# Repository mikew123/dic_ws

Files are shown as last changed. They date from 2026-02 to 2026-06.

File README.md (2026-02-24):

# Platform control

The platform creates a wifi signal that needs to be connected to:<br>
SSID: "tech" PASSWORD: "Art723!!"<br>
Use a web browser to connect to "htpp://192.168.4.1"<br>
Configure the HOME offset degrees and periodic rotation period and degrees of rotation.<br>
<br>
The platform must be put in the "HOME" position by pressing the "HOME" button which points in the same direction each time after the homeing sequence completes. The homing sequence rotates 1 or 2 times before stopping.<br>
After the homeing is complete the "RUN" button starts the periodic rotations. The platform rotates the amount set by the periodic rotation amount and stops until the the next rotation starts. The rotations occur an the precise intervlas set by the periodic period.<br>

# Platform views

View of the bottom panel of the platform from the top. The housing in the center send the AC power to the top using a rotary coupler and has a 6" bearing on its top which fits into the ring on the bottom panel. There are 4 caster wheels and a large motor with a drive wheel which causes the top panel to rotate. Next to the motor is the motor controller. The limit switches are mounted so that the humps on the top panel activate them as the pass over the switch. <br>
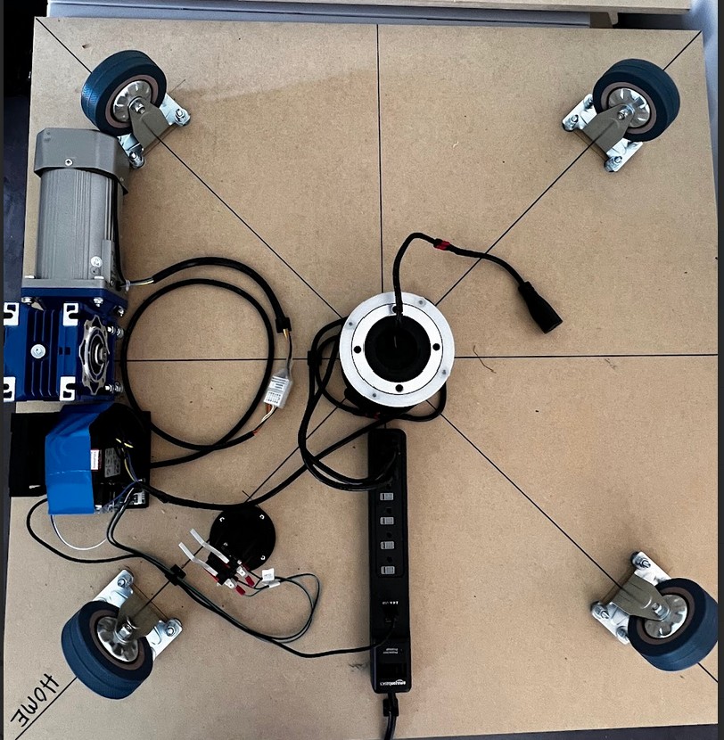
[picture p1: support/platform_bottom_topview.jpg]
platform bottom top view
 <br>
View of the top panel of the platform from the bottom. The center ring is used to keep the top panel centered using the bearing on the bottom panel. There are 4 humps which activate the limit switches on the bottom panel. <br>
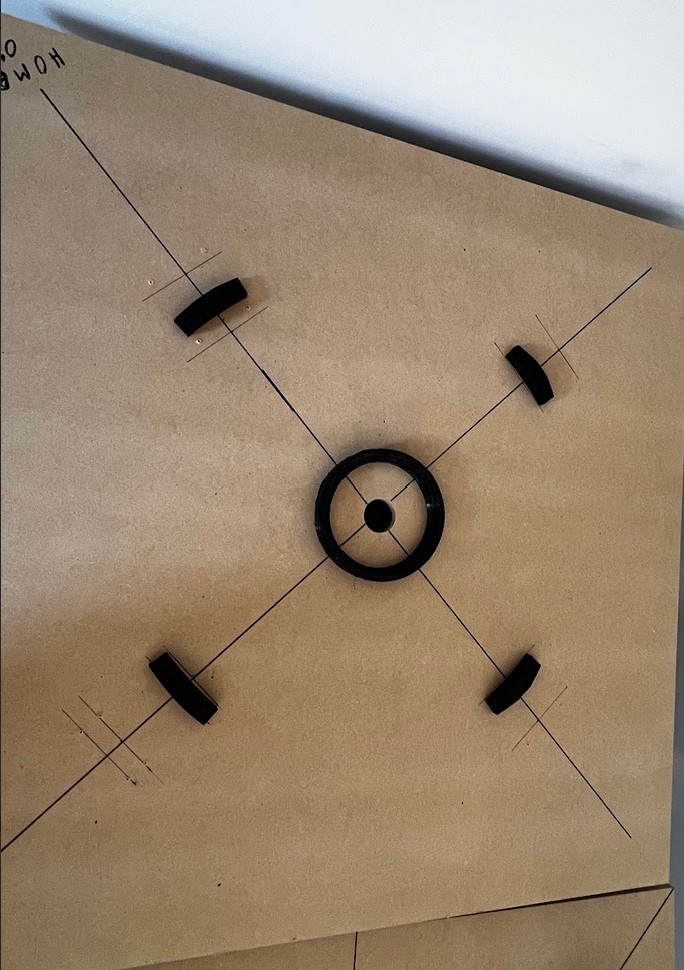
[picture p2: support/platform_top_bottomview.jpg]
platform top bottom view
 <br>
View of the bottom panel of the platform from the side.
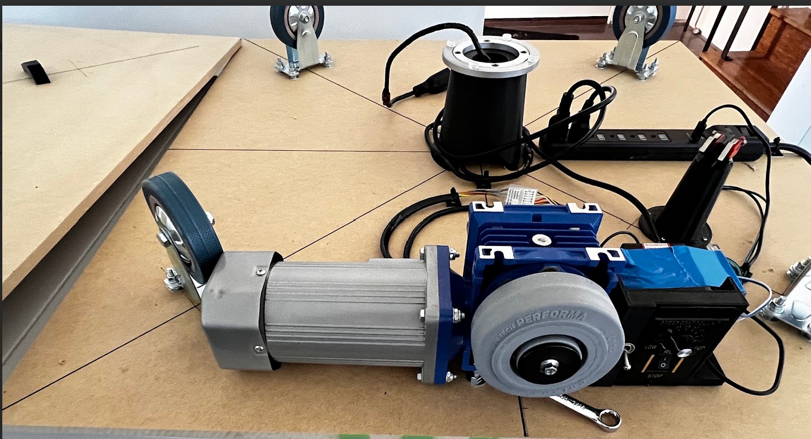
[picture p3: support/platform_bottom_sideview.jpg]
platform bottom sideview
 <br>
The height of the drive wheel cn be adjusted using the bolt nuts to raise the motor. The bolt threads provide  fine resolution in height adjustment.
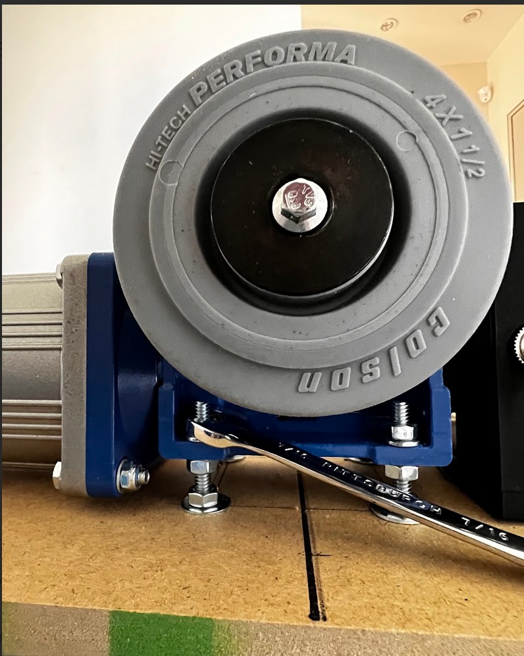
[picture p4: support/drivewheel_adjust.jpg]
drivewheel adjust
 <br>
View of the motor controller. The rotation rate is controlled by the SPEED knob. The switch to the left controlls CW and CCW platform rotation. The microcontroller on the right side (blue light) has the wifi interface and performs the periodic rotations by turning the motor ON/OFF.
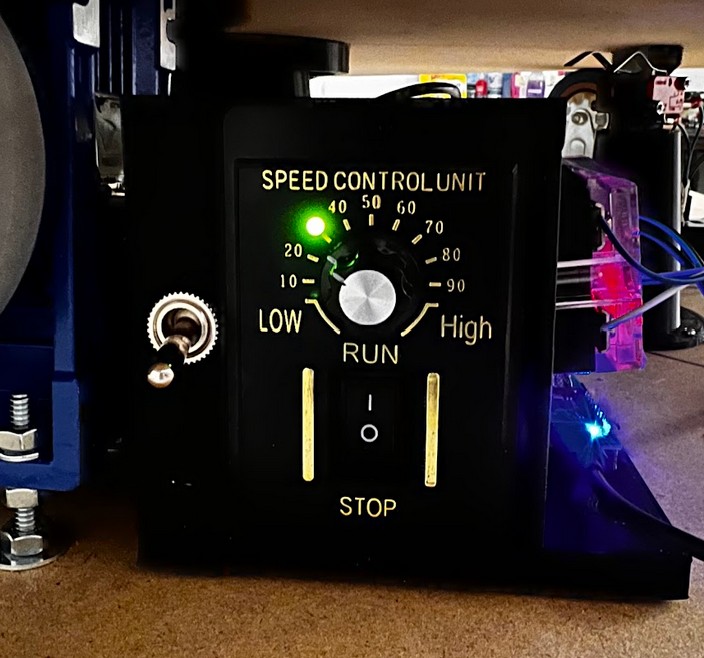
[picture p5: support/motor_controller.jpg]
motor_controller
 <br>
Top of the webpage which has the configuration.
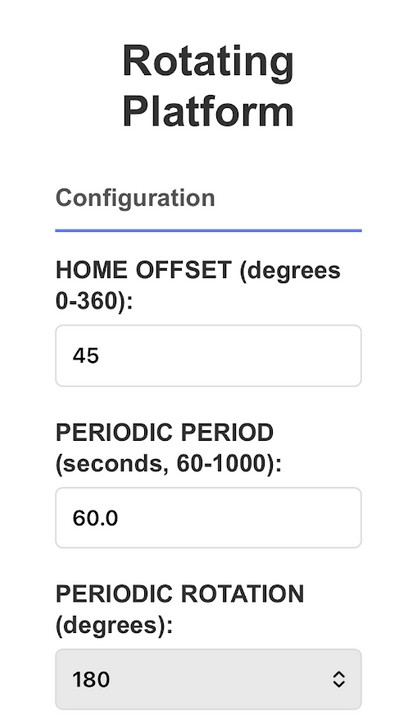
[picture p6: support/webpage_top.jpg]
 <br>
Bottom of the webpage which has the control buttons.
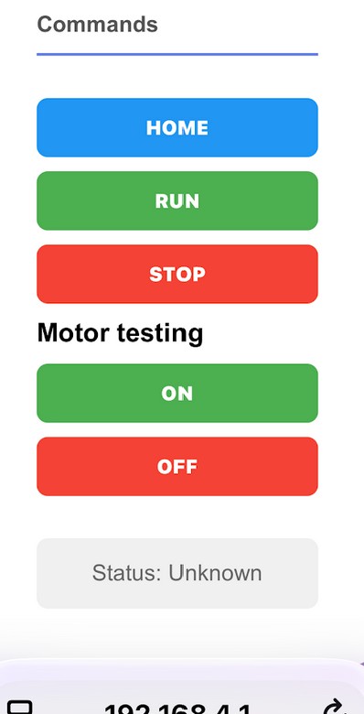
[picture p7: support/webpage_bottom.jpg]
platform bottom sideview
 <br>

# Micro-controller

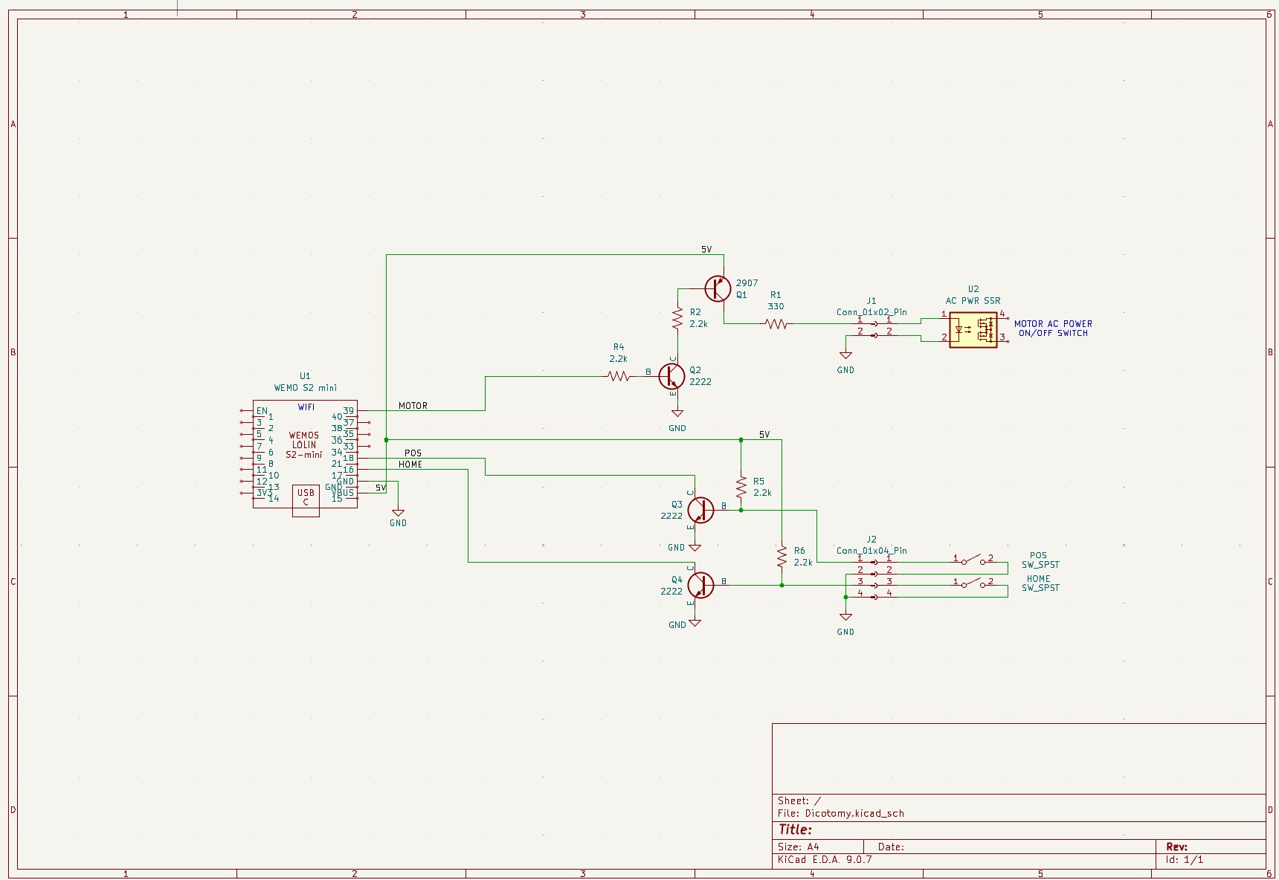
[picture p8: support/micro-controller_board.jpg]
micro controller board
 <br>
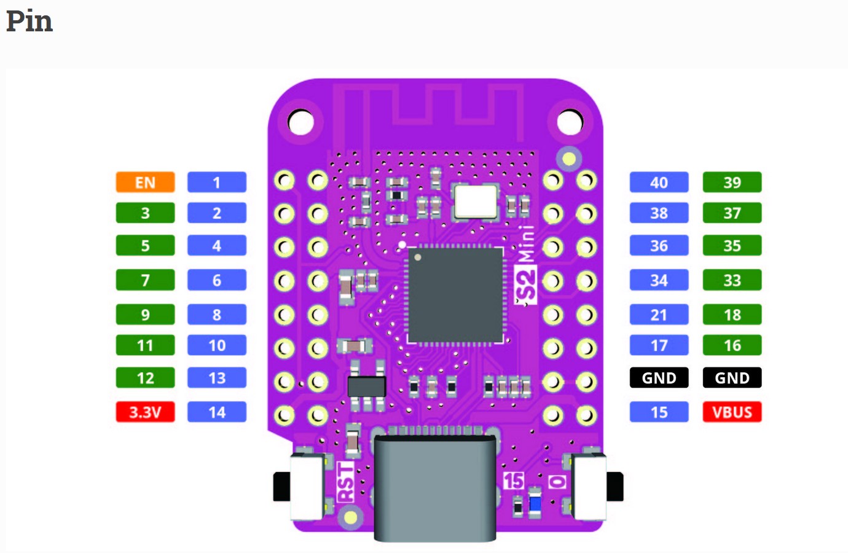
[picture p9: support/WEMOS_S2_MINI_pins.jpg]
micro controller
 <br>

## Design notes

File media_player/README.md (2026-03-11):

# Dicotomy of Passion Media player
There are 2 projectors in the house pointing out different side of the house in the rotating sculpture which are playing different videos on a timed loop. The will be audio from each video eminating from the side of the house the video is playing from. There is AC power in the sculpure to run the media.<br>
The player could be a MAC/PC or a Raspberry Pi with 2 HDMI interfaces. The audio would come from the 3.5mm audio jack on each of the 2 projectors. The sound can come from 2 portable speakers using the audio signal from the 3.5mm audio jacks. The portable speakers can have charging cables plugged in supplying power instead of only the internal batteries.<br>

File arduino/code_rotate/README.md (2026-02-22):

# Rotating Platform Control - code_rotate

## Overview
Arduino code for the ESP32 (WEMOS S2-mini) microcontroller that controls a rotating platform. The platform can be rotated to a HOME position and then periodically rotated with precise timing and no accumulated drift.

## Hardware Interface

### Motor Control
- **Pin 39**: Motor control digital output
  - HIGH: Motor ON
  - LOW: Motor OFF

### Position Limit Switches
Two limit switches with transistor voltage level converters (5V to ESP32 compatible):

- **Pin 16 (HOME_SWITCH_PIN)**: HOME position limit switch
  - Triggered when platform reaches position 0 (HOME position)
  - Used to establish home position reference
  - Part of position detection system (every 90 degrees)

- **Pin 18 (POSITION_SWITCH_PIN)**: Position limit switch
  - Triggered at each 90-degree offset from HOME
  - Positions: 90°, 180°, 270° (HOME is 0°)
  - Used to measure rotation speed (RPM) between triggers
  - Also used to detect HOME position (both switches trigger at home)

### Switch Characteristics
- Both switches use LOW to HIGH transitions to signal detection
- 100ms debounce time required to filter glitches
- All 4 discrete positions (0°, 90°, 180°, 270°) are detectable

## WiFi & Web Interface

### Network
- **Mode**: Access Point (AP)
- **SSID**: "dicotomy"
- **Password**: "passion"
- **Port**: 80 (HTTP)

### Web Page Features
The web interface provides configuration and control:

#### Configuration Parameters
1. **HOME OFFSET** (0-360 degrees)
   - Degrees to rotate after HOME switch is detected
   - Establishes the starting position for periodic rotations
   - Valid range: 0-360

2. **PERIODIC PERIOD** (60-1000 seconds, 1 decimal place)
   - Time between start of each periodic rotation
   - Maintains precise timing with no accumulated drift
   - Example: 60.0 means rotations start every 60 seconds

3. **PERIODIC ROTATION** (degrees in 90° increments)
   - Valid options: 90, 180, 270, 360, 450, 540, 630, 720
   - Amount to rotate in each periodic cycle
   - Example: 540 = 1.5 rotations

#### Commands
- **HOME**: Rotate platform to HOME position + HOME OFFSET
  - Motor must be OFF to start HOME sequence
  - Detects HOME switch twice, then rotates to offset position
  
- **RUN**: Start periodic rotations
  - Only available after HOME sequence completes
  - Rotations start immediately and repeat every PERIODIC PERIOD
  - No accumulated timing drift

- **STOP**: Stop motor and periodic rotations
  - Halts any active rotation
  - Motor transitions to OFF state

## Motion Control Details

### Rotation Tracking
- Four hardware-detected positions: 0° (HOME), 90°, 180°, 270°
- Additional positions calculated based on HOME OFFSET (up to 360°)
- Rotation speed (RPM) measured from time between POSITION switch triggers (90° apart)

### HOME Sequence (Example)
1. User clicks HOME button
2. Motor rotates until HOME switch triggers (first detection)
3. Motor continues until HOME switch triggers again (second detection)
4. Motor rotates additional HOME OFFSET degrees
   - If offset divides evenly by 90°, uses position switches
   - Remaining degrees (< 90°) calculated using estimated RPM
5. Motor stops at final home position
6. Platform ready for RUN command

### Periodic Rotation Sequence (Example)
1. Home position confirmed
2. User clicks RUN button
3. First rotation starts immediately
4. Platform rotates PERIODIC_ROTATION degrees (using position switches and time)
5. Motor stops
6. Precisely PERIODIC_PERIOD seconds after RUN was issued, rotation #2 starts
7. Rotations continue: #3 starts at 2×PERIODIC_PERIOD, etc.
8. No accumulated time drift between rotations

### Timing Precision
- Rotations are scheduled from the RUN button time, not from motor stop time
- This eliminates accumulated drift even if individual rotations take slightly different times
- Each periodic rotation starts at: RUN_TIME + (N × PERIODIC_PERIOD)

## Code Architecture

### State Machine
```
MOTOR_OFF → HOMING → HOME_COMPLETE → PERIODIC_RUNNING ↔ PERIODIC_WAITING
   ↑                      ↑                              ↑
   +--- STOP command -----+-------------- STOP command --+
```

### Key Functions
- `updateSwitchStates()`: Debounces limit switch inputs
- `onHomeSwitchTriggered()`: Handles HOME switch logic
- `onPositionSwitchTriggered()`: Tracks rotation and measures RPM
- `updateMotorControl()`: Manages motor timing and state transitions
- `handleHome()`, `handleRun()`, `handleStop()`: Web command handlers

### Important Variables
- `motorState`: Current operational state
- `homeCountDuringHome`: Tracks HOME switch triggers during homing
- `positionCountDuringRotation`: Counts 90° position switches
- `estimatedRPM`: Calculated speed from switch timing
- `runCommandTime`: Reference time for periodic rotation scheduling
- `lastRotationNumber`: Prevents multiple starts of same rotation

## Validation Rules
All configuration values are validated:
- HOME OFFSET: Must be 0-360 (integer)
- PERIODIC PERIOD: Must be 60-1000 (float with 1 decimal)
- PERIODIC ROTATION: Must be one of [90, 180, 270, 360, 450, 540, 630, 720]

Invalid configurations are rejected with error messages.

## Serial Debug Output
Monitor serial port (115200 baud) for debugging information:
- WiFi connection status
- Web server startup
- Switch trigger events
- RPM measurements
- Command execution logs
- State transitions

## Safety Notes
- Motor OFF when power applied (safe default)
- HOME sequence required before RUN
- STOP always available to halt rotation
- Configuration validates all inputs
- 100ms debounce prevents false triggers

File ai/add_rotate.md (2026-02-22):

# Overview
Modify the existing arduino project "arduino/code_onoff" code which was created with the requirements in the "add_onoff.md" file to make a new arduino project "arduino/code_rotate". The platform can be rotated to a HOME position then periodically rotated relative to the HOME position. Fix any errors after generating the code.

# Hardware interface to platform
The platform motor control and position limit switch sensors connect to digital pins of the ESP32.

## Position limit switches
There are 2 limit switches with transitors for voltage level conversion. High is when the switches are at the home location (position 0) or one of the 3 positions at 90, 180 and 270 degree offsets from HOME. 
- The HOME switch is on pin 16. The home position switch is is triggered at position 0 which sets the platform alignment.
- The POSITION switch is on pin 18. The position switch gets triggered at each of the 3 positions 90 degrees apart.

# Ethernet/wifi
Modify the existing served web page with configuration inputs and 2 new buttons.

### Configurations
Validate all configurations are positive.
- HOME OFFSET: 
Degrees offset after the HOME limit switch is sensed. This establishes the platform periodic rotation start position after the HOME command is given. This is positive integer in degrees. The range is 0 to 360 degrees.
- PERIODIC PERIOD: The amount of time between start of each periodic rotation. This is positive floating seconds with 1 decimal place. The range is limited to 60 to 1000 seconds.
- PERIODIC ROTATION: This is the amount of rotation the platform performs after each periodic positioning period. It is a integer pick list with 90 degrees incriments of [90, 180, 270, 360, 450, 540, 630, 720].

### Commands
Add these new command buttons to the existing ON and OFF buttons
- HOME: Rotate the platform to the HOME OFFSET from the last HOME limit switch trigger. The motor must be OFF to start the HOME sequence.
- RUN: Start the periodic rotations. The motor must be OFF/STOP and a HOME sequence executed.
- STOP: Stop the periodic rotations, turns the motor OFF.

## Details
- The code starts in the MOTOR OFF state
- Any motor ON/OFF commands stop the periodic rotations if active.
- The HOME sequence can be started any time the motor is OFF/STOP
- The RUN sequence can only perform after the HOME sequence is finished and the motor is OFF/STOP.

### Rotations in degrees.
The HOME and POSITION limit switches create a command signal when switching LOW to HIGH. This transition LO to HIGH and HIGH to LOW can have glitches which must be filtered out, use a 100 ms requirment to detect HI or LOW
- There are only 4 hardware detected positions 0(HOME), 90, 180 and 270 using the limit switches. 
- The home offset can be set to any positive rotation in degrees up to 360. 
- Rotations are tracked using the home and position limit switches and a rotataion estimate using the measured RPM when the rotation is supposed to stop between limit switch triggers. The RPM is measured using the time between each position limit switch trigger which are spaced 90 degrees. 
- When the HOME command is triggered the HOME sequence must rotate to detect the HOME switch location twice before continuing for the amount of HOME OFFSET using limit switch triggers for each 90 degrees of the offset and the remainder of the offset degrees is rotated using the estimated rate of rotation; this offset position is the start position of the periodic rotations.
- When the RUN command is triggered the platform is rotated at the configured periodic period rate for the amount of degrees configured in the periodic rotation. The periodic rotations start precisely every periodic period with no drift, the rotation will complete before the next rotation starts. The periodic rotation is in increments of 90 degrees which uses the limit switches to measure. After the last limit switch for the periodic period is triggered then the HOME offset degrees are added to the rotation.

# Examples
- After the HOME sequence completes and a RUN command is triggered, the PERIODIC ROTATION cycle sequences start immediately and continue precisely every PERIODIC PERIOD. There must be no accumulated time errors between each periodic rotation cycle, i.e. the 10th periodic cycles starts precisely at 10*(PERIODIC PERIOD) seconds after the RUN button is triggered.

## Example 1
- The HOME OFFSET is 0 degrees
- The PERIODIC ROTATION is 540 degrees (1 1/2 rotations)
- The PERIODIC PERIOD is 60 seconds
- When the HOME command is triggered the platform rotates more than 1 rotation, it stops immediately after the 2nd HOME limit switch trigger occurs since the OFFSET is 0 degrees.
- Immediately when the RUN command is triggered the platform starts to rotates 1 1/2 rotations before stopping immediately after the 6th POSITION limit switch is detected since the ROTATION is exactly 6 X 90 degrees and the HOME offset is 0 degrees.
- 60 seconds after the RUN command is triggered a 2nd rotation starts. Rotations start after each 60 second period until a STOP or OFF command.

## Example 2
Assume the rotation speed is 10.0 RPM (6 seconds per rotation) which is measured while rotating between 90 degree limit switch triggers.
- The HOME OFFSET is 15 degrees
- The PERIODIC ROTATION is 540 degrees (1 1/2 rotations)
- The PERIODIC PERIOD is 60 seconds
- When the HOME command is triggered the platform rotates more than 1 rotation, it stops 15 degrees after the 2nd HOME limit switch trigger occurs since the HOME OFFSET is 15 degrees. The 15 degrees rotation time after the 2nd HOME switch would be 0.25 seconds at 10 RPM. 
- Immediately after the RUN command the platform rotates 1 1/2 rotations relative to the HOME position. The platform rotates for 6 limit switch triggers then continues to rotate 15 degrees more based on the HOME OFFSET which is 0.25 seconds based on the estimated RPM. Since the RERIODIC ROTATION of 540 degrees is exactly 6 POSITION switch triggers (90 degrees between triggers) the 15 degree HOME OFFSET is the offset for each rotation.
- 60 seconds after the RUN command is triggered a 2nd rotation starts. Rotations start after each 60 second period until a STOP or OFF command.

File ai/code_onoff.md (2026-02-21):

# Overview
Generate Arduino code in the arduino folder for the WEMOS S2-mini ESP32 S2 micro controller. The code is used to control a rotating platform using a motor using a web page. Fix any errors after generating the code.

# Hardware interface to platform
The platform motor control connects to a digital pin of the ESP32.

## Motor control
The motor is controlled with a digital output to transistors to voltage level convert to 5V.
- Use pin 39. When high the motor is ON, when low the motor is OFF

# Ethernet/wifi
Create a wifi interface in AP mode on the ESP32 creating a wifi network on which to serve web page(s). The ssid and password can be changed by editing the code file.
- The ssid is dicotomy
- The password is passion

## Web page
Serve a web page that sends commands the ESP32. The web page launches when a browser connects to the IP and when the external device performs a connection to the AP wifi. The web page should be formated for a browser on phone screen.

### Commands
These are "buttons" on the 
- ON: Turn the motor ON.
- OFF: Turn the motor OFF.

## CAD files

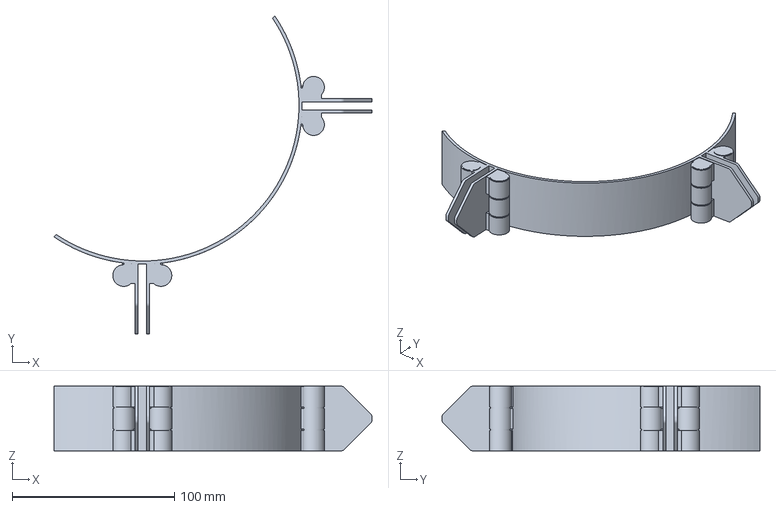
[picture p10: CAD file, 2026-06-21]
3dPrinted/Dicotomy-FinAttachTop.3mf
195.9 x 195.9 x 40.0 mm

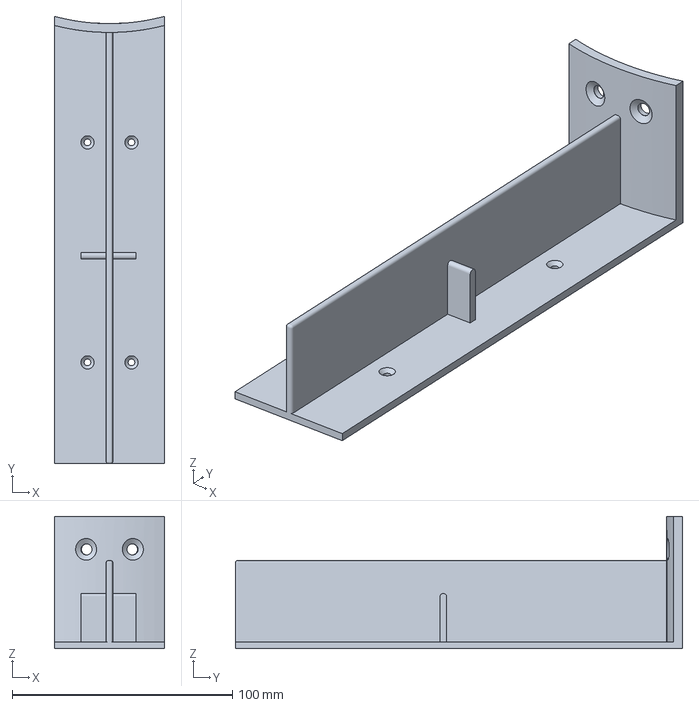
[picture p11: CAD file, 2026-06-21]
3dPrinted/Dicotomy-HouseWallTubeAttach.3mf
50.0 x 203.3 x 60.0 mm

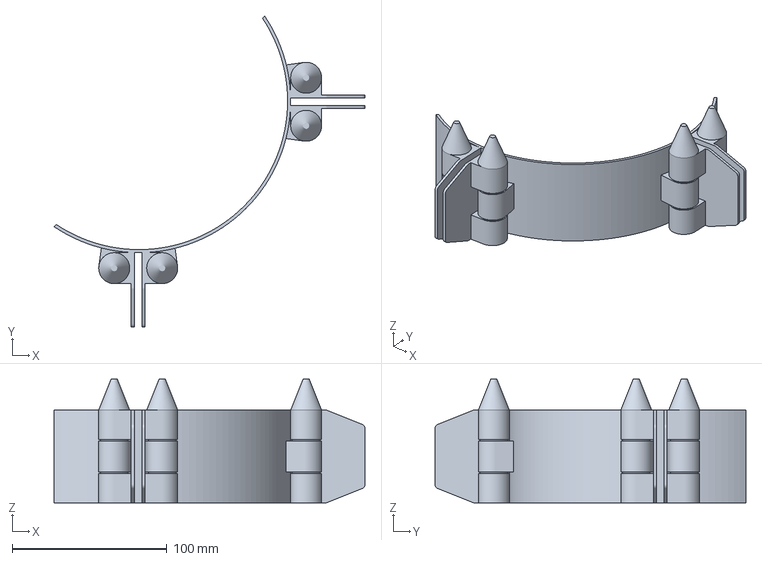
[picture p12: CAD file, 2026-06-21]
3dPrinted/Dicotomy-FinAttachBot.3mf
200.9 x 200.9 x 80.0 mm

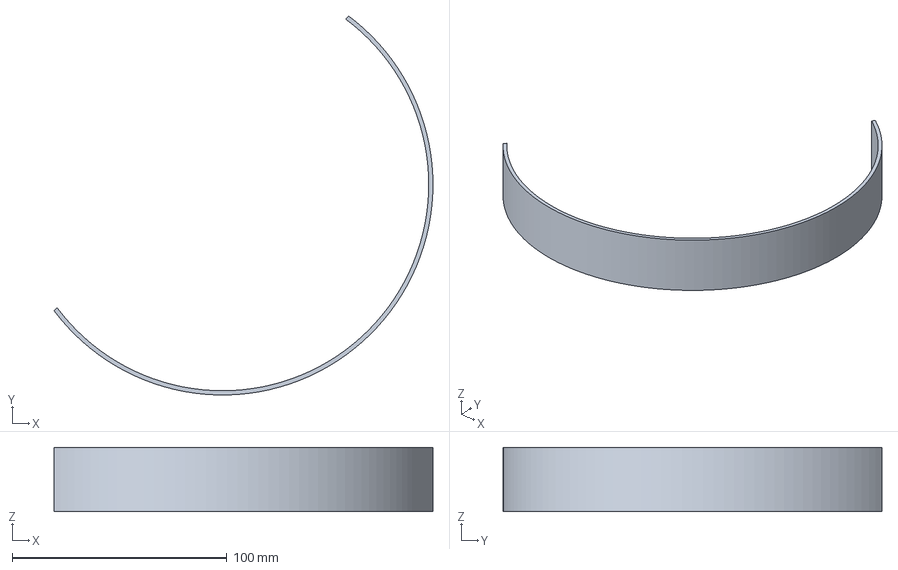
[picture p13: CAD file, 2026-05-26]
3dPrinted/Dicotomy-RocketBandBot.3mf
176.4 x 176.4 x 30.0 mm

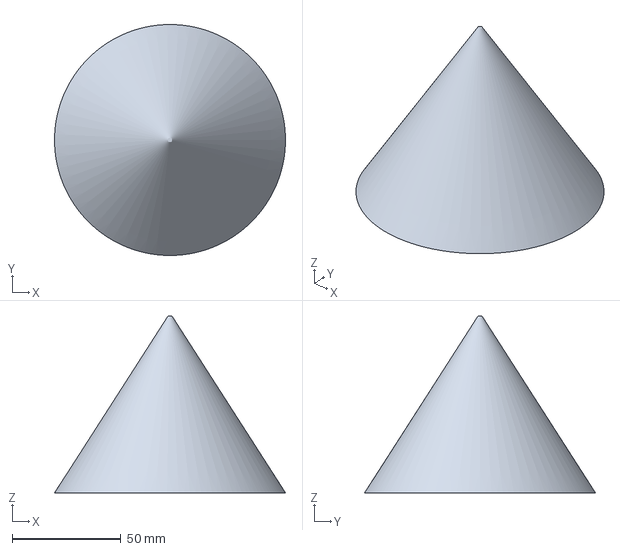
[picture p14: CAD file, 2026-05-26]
3dPrinted/Dicotomy-RocketTipTop.3mf
106.0 x 106.0 x 81.0 mm

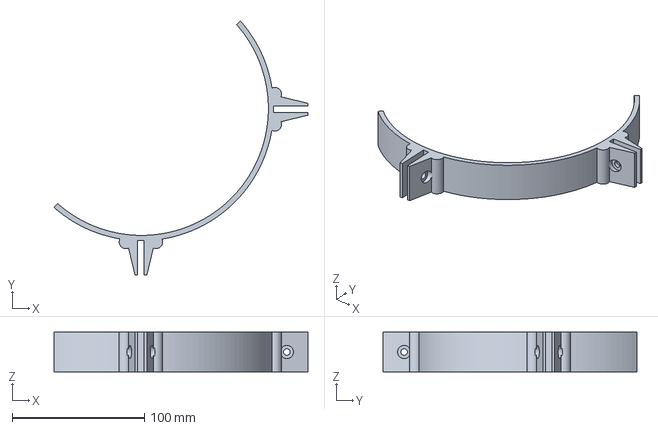
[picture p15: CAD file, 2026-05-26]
3dPrinted/Dicotomy-FinAttach.3mf
192.3 x 192.3 x 30.0 mm

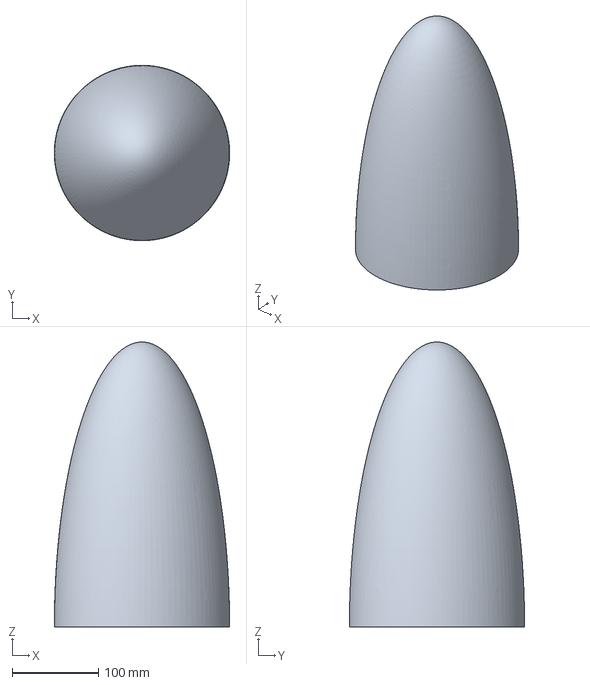
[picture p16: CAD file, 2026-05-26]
3dPrinted/Dicotomy-RocketTip.3mf
203.0 x 203.0 x 330.0 mm

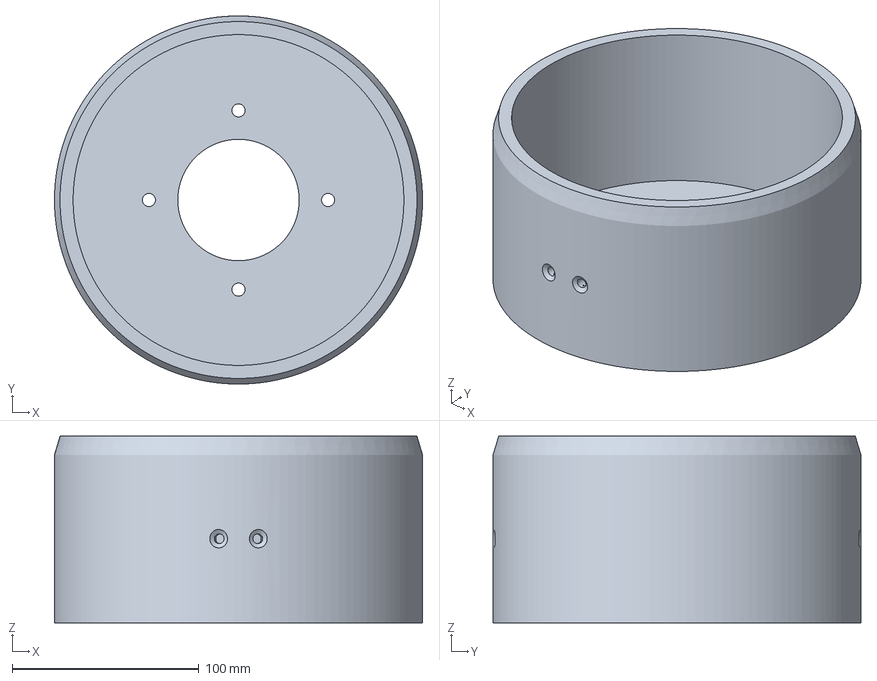
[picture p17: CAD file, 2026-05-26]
3dPrinted/Dicotomy-RocketMount.3mf
197.2 x 197.1 x 100.0 mm

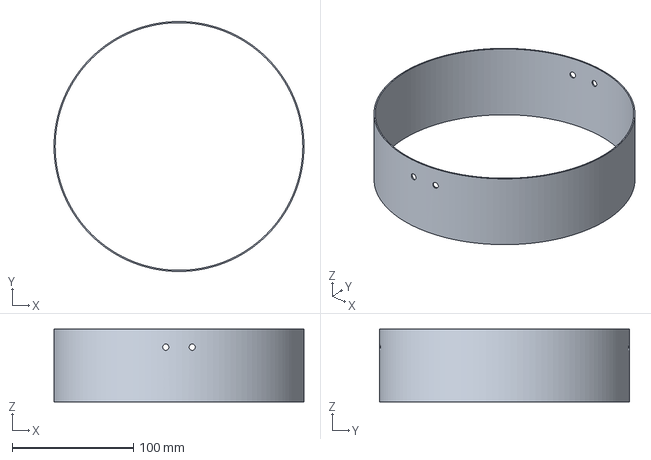
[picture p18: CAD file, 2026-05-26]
3dPrinted/Dicotomy-MountHoleTemp.3mf
206.2 x 206.1 x 60.0 mm

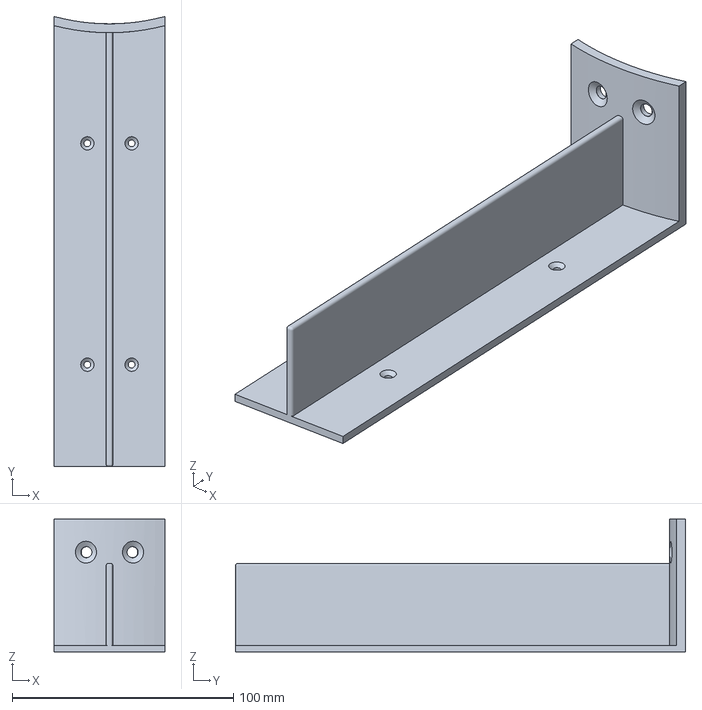
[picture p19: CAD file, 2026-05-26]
3dPrinted/Dicotomy-FloorWallTubeAttach.3mf
50.0 x 203.3 x 60.0 mm

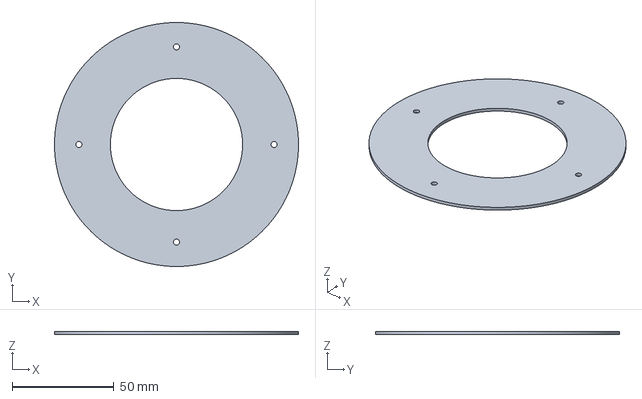
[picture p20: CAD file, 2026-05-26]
3dPrinted/Dicotomy-RocketMountDrillTemplate.3mf
120.0 x 120.0 x 1.50 mm

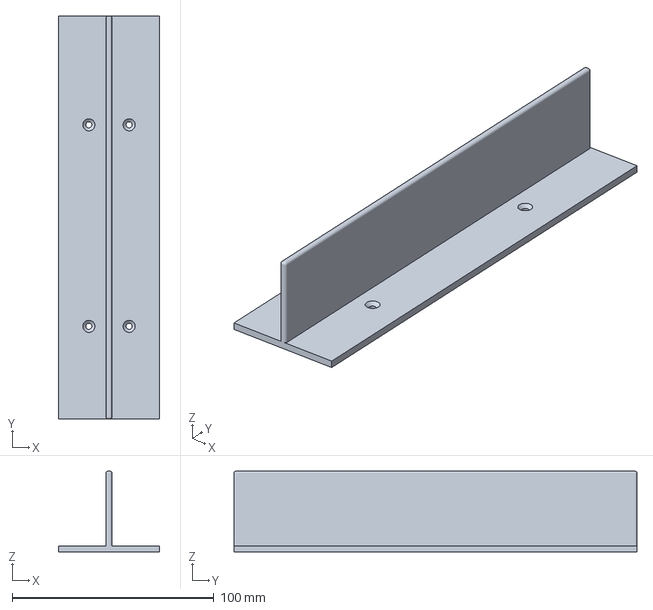
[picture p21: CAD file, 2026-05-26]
3dPrinted/Dicotomy-FloorWallAttach.3mf
50.0 x 200.0 x 40.0 mm

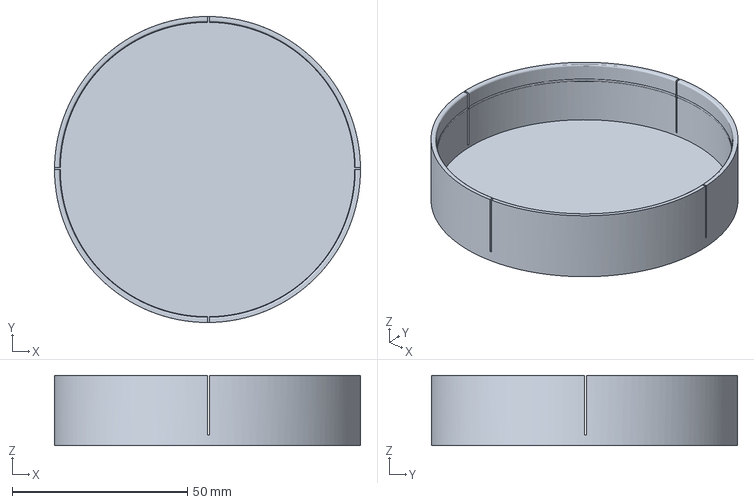
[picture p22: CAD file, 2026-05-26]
3dPrinted/Dicotomy-LensCap.3mf
87.3 x 87.3 x 20.0 mm

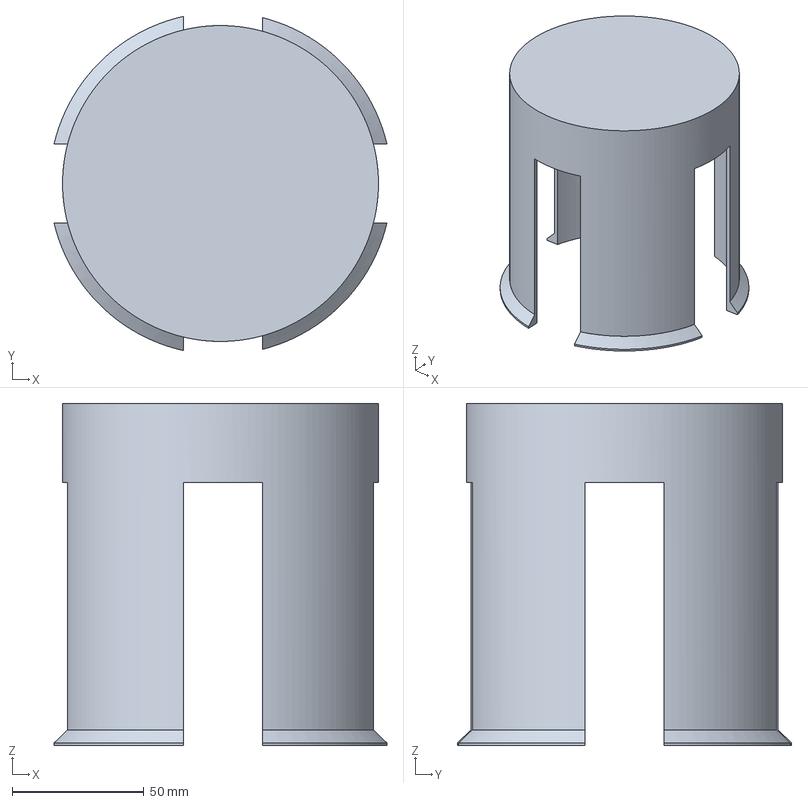
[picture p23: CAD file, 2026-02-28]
3dPrinted/Dicotomy-SwitchProtector.3mf
126.5 x 126.9 x 130.0 mm

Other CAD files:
3dPrinted/Dicotomy.FCStd
3dPrinted/Dicotomy-SwichProtectorClips.3mf
3dPrinted/Dicotomy-clip.3mf
3dPrinted/Dicotomy-ElecMount.3mf
3dPrinted/Dicotomy-CenterHousing.3mf
3dPrinted/Dicotomy-CenteringRing.3mf
3dPrinted/Dicotomy-HumpCurved.3mf
3dPrinted/Dicotomy-LimitSwHump.3mf
3dPrinted/Dicotomy-LimtSwMount.3mf

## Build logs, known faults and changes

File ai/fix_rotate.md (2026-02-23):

Add code to turn on LED=255 while motor is runing and LED=50 when not running
OR the HOME switch with the POSITION switch  so that all 4 90 deg positions are triggered
Start position count at -1 after 2nd HOME switch is detected while homing, this is used to offset the fact that the HOME switch added a POSITION count
Add motor ON and OFF buttons to web page that un-conditionally turn the motor ON or OFF. A MOTOR_ON state is added
HOME OFFSET remainder degree rotation is 1/10 of what it should be. i.e. OFFSET = 3 stops about 30 degrees after physical HOME.
The DELTATIME_MAX between 90 degree POSITION switches needs to be 60 seconds so the motor can operate at the slowest speed.

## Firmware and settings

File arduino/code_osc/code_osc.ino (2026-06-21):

#include <WiFi.h>
#include <WebServer.h>

// #include <WiFiServer.h>
#include <WiFiClient.h>
#include <WiFiUdp.h>

#include <Preferences.h>
#include <cstring>
#include <FreeRTOS.h>
#include "ledStuff.h"

// WiFi credentials for AP mode (fallback)
const char* apSSID = "dicotomy";
const char* apPassword = "passion";

// WiFi connection mode and status
Preferences preferences;
enum ConnectionMode {
  CONN_MODE_AP,      // Access Point (fallback)
  CONN_MODE_STA,     // Station (connected to external WiFi)
  CONN_MODE_ATTEMPTING // Attempting to connect to external WiFi
};
ConnectionMode currentWiFiMode = CONN_MODE_AP;
String staSSID = "";
String staPassword = "";
unsigned long wifiConnectStartTime = 0;
const unsigned long WIFI_CONNECT_TIMEOUT = 15000; // 15 seconds to connect

// Constants
const uint16_t WEB_SERVER_PORT = 80;
const uint16_t OSC_PORT = 53000;

bool udpStarted = false;

// create ethernet stuff
WiFiUDP udp;

WebServer server(WEB_SERVER_PORT);
// WiFiServer server(WEB_SERVER_PORT);

// Create LED controller for blinking non-blocking etc
ledStuff led;

// Hardware pins
const int MOTOR_PIN = 39;
const int HOME_SWITCH_PIN = 16;
const int POSITION_SWITCH_PIN = 18;

// Motor control states
enum MotorState {
  MOTOR_OFF,
  MOTOR_ON,
  HOMING,
  HOME_COMPLETE,
  PERIODIC_RUNNING,
  PERIODIC_WAITING,
  OSC_MOTOR_ON,
  OSC_MOTOR_OFF,
  OSC_ROTATE_NOW,
  OSC_ROTATE_TO_0,
  OSC_ROTATE_TO_90,
  OSC_ROTATE_TO_180,
  OSC_ROTATE_TO_270,
  OSC_ROTATE_90,
  OSC_ROTATE_180,
  OSC_ROTATE_360
};

// Configuration parameters
float periodicPeriod = 60.0;           // 60-1000 seconds with 1 decimal
int periodicRotation = 180;             // [90, 180, 270, 360] degrees

// Global state
MotorState motorState = MOTOR_OFF;
int homeCountDuringHome = 0;           // Count of HOME switch triggers during homing
int positionCountDuringRotation = 0;   // Count of POSITION switch triggers during rotation
bool homeSwitchDetected = false;
bool positionSwitchDetected = false;
bool homeSwitchLastState = LOW;
bool positionSwitchLastState = LOW;
int lastRotationNumber = -1;           // Track which rotation we're on

// Debounce constants
const int DEBOUNCE_TIME = 10;         // 10ms debounce requirement
// Wait time for Serial port connection before continuing without
const int SERIALWAIT = 10000; // 10 sec


void setup() {
  // LED blinks while waiting for serial connection
  led.ledBlink(1000, 255, 250, 0, 250);

  Serial.begin(115200);
  uint32_t t0 = millis();
  while(!Serial) {
    // Wait for USB serial connection before continuing without
    if((millis()-t0) > SERIALWAIT) break;
    delay(100);
  }
  led.stopBlink(50);

  // Initialize pins
  pinMode(MOTOR_PIN, OUTPUT);
  digitalWrite(MOTOR_PIN, LOW);
  pinMode(HOME_SWITCH_PIN, INPUT_PULLUP);
  pinMode(POSITION_SWITCH_PIN, INPUT_PULLUP);
  
  // Initialize preferences
  preferences.begin("wifi-config", false);
  
  // Try to load and connect to saved WiFi in STA mode
  loadWiFiCredentials();
  if (staSSID.length() > 0) {
    Serial.println("\nAttempting to connect to saved WiFi...");
    connectToExternalWiFi();
  } else {
    // No saved WiFi, start in AP mode immediately
    Serial.println("\nNo saved WiFi credentials. Starting in AP mode...");
    startAPMode();
  }
  
  // Setup web server routes
  server.on("/", handleRoot);
  server.on("/config", handleConfig);
  server.on("/on", handleMotorOn);
  server.on("/off", handleMotorOff);
  server.on("/home", handleHome);
  server.on("/run", handleRun);
  server.on("/stop", handleStop);
  server.on("/status", handleStatus);
  server.on("/scan", handleScanWiFi);
  server.on("/wifi", handleWiFiConfig);
  server.on("/wifiStatus", handleWiFiStatus);
  server.onNotFound(handleNotFound);
  
  server.begin();
  Serial.println("Web server started");
}

void loop() {
  server.handleClient();
  updateSwitchStates();
  updateMotorControl();
  checkWiFiConnection();
  checkOSC();
  
  // MRW: LED ON when motor is on
  if(digitalRead(MOTOR_PIN)) 
    led.setIntensity(255);
  else 
    led.setIntensity(50);

}


////////////////////////////////////////////////////////////////////////
// WiFi Management Functions

// Load WiFi credentials from preferences/EEPROM
void loadWiFiCredentials() {
  preferences.begin("wifi-config", true);  // true = read-only mode first
  staSSID = preferences.getString("ssid", "");
  staPassword = preferences.getString("password", "");
  preferences.end();
  
  if (staSSID.length() > 0) {
    Serial.print("Loaded WiFi SSID from EEPROM: ");
    Serial.println(staSSID);
  }
}

// Save WiFi credentials to preferences/EEPROM
void saveWiFiCredentials(String ssid, String password) {
  preferences.begin("wifi-config", false);  // false = read-write mode
  preferences.putString("ssid", ssid);
  preferences.putString("password", password);
  preferences.end();
  Serial.print("Saved WiFi credentials to EEPROM: ");
  Serial.println(ssid);
}

// Start AP mode (Access Point)
void startAPMode() {
  Serial.println("Starting WiFi AP Mode...");
  WiFi.mode(WIFI_AP);
  WiFi.softAP(apSSID, apPassword);
  
  IPAddress IP = WiFi.softAPIP();
  Serial.print("AP IP address: ");
  Serial.println(IP);
  currentWiFiMode = CONN_MODE_AP;
  udpStarted = false;  // Reset UDP listener
}

// Connect to external WiFi (STA mode)
void connectToExternalWiFi() {
  if (staSSID.length() == 0) {
    Serial.println("ERROR: No WiFi SSID to connect to");
    return;
  }
  
  Serial.print("Connecting to WiFi: ");
  Serial.println(staSSID);
  
  WiFi.mode(WIFI_STA);
  WiFi.begin(staSSID.c_str(), staPassword.c_str());
  
  currentWiFiMode = CONN_MODE_ATTEMPTING;
  wifiConnectStartTime = millis();
}

// Check WiFi connection status and handle transitions
void checkWiFiConnection() {
  if (currentWiFiMode == CONN_MODE_ATTEMPTING) {
    unsigned long elapsed = millis() - wifiConnectStartTime;
    
    if (WiFi.status() == WL_CONNECTED) {
      Serial.println("\nWiFi connected!");
      Serial.print("IP address: ");
      Serial.println(WiFi.localIP());
      currentWiFiMode = CONN_MODE_STA;
      udpStarted = false;  // Reset UDP listener to start on new network
    } else if (elapsed > WIFI_CONNECT_TIMEOUT) {
      Serial.println("WiFi connection timeout. Switching to AP mode...");
      startAPMode();
    }
  } else if (currentWiFiMode == CONN_MODE_STA) {
    // Monitor STA connection
    if (WiFi.status() != WL_CONNECTED) {
      Serial.println("WiFi connection lost. Switching to AP mode...");
      startAPMode();
    }
  }
}

////////////////////////////////////////////////////////////////////////
// OSC STUFF

//Decoded OSC messages
bool calibrateHome = false;
bool motorOn = false;
bool motorOff = false;
bool rotateTo0 = false;
bool rotateTo90 = false;
bool rotateTo180 = false;
bool rotateTo270 = false;
bool rotate90 = false;
bool rotate180 = false;
bool rotateNow = false;

class OSCDecoder {
public:
    struct OSCMessage {
        String address;
        String typeTag;
        struct Argument {
            char type;  // 'i', 'f', 's', 'b'
            union {
                int32_t intValue;
                float floatValue;
            };
            String stringValue;
            uint8_t blobValue[256];
            int blobSize;
        };
        static const int MAX_ARGS = 32;
        Argument args[MAX_ARGS];
        int argCount;
    };

    static String padString(const uint8_t* data, int& index, int maxLen) {
        String result;
        while (index < maxLen && data[index] != 0) {
            result += (char)data[index];
            index++;
        }
        index++;  // Skip null terminator
        // Pad to 4-byte boundary
        index += (4 - (index % 4)) % 4;
        return result;
    }

    static int32_t readInt32(const uint8_t* data, int& index) {
        int32_t value;
        memcpy(&value, &data[index], 4);
        // Convert from big-endian to little-endian if needed
        value = __builtin_bswap32(value);
        index += 4;
        return value;
    }

    static float readFloat32(const uint8_t* data, int& index) {
        uint32_t intBits;
        memcpy(&intBits, &data[index], 4);
        intBits = __builtin_bswap32(intBits);
        float value;
        memcpy(&value, &intBits, 4);
        index += 4;
        return value;
    }

    static OSCMessage* decodeMessage(const uint8_t* data, int length) {
        OSCMessage* msg = new OSCMessage();
        int index = 0;
        msg->argCount = 0;

        // Read address pattern
        msg->address = padString(data, index, length);

        // Read type tag string
        msg->typeTag = padString(data, index, length);

        // Parse arguments based on type tag
        if (msg->typeTag.startsWith(",")) {
            String types = msg->typeTag.substring(1);  // Remove leading comma

            for (int i = 0; i < types.length() && msg->argCount < OSCMessage::MAX_ARGS; i++) {
                char typeChar = types[i];
                OSCMessage::Argument& arg = msg->args[msg->argCount];
                arg.type = typeChar;
                arg.blobSize = 0;

                if (typeChar == 'i') {  // int32
                    arg.intValue = readInt32(data, index);
                    msg->argCount++;
                }
                else if (typeChar == 'f') {  // float32
                    arg.floatValue = readFloat32(data, index);
                    msg->argCount++;
                }
                else if (typeChar == 's') {  // string
                    arg.stringValue = padString(data, index, length);
                    msg->argCount++;
                }
                else if (typeChar == 'b') {  // blob
                    int32_t blobSize = readInt32(data, index);
                    if (blobSize <= 256) {
                        memcpy(arg.blobValue, data + index, blobSize);
                        arg.blobSize = blobSize;
                    }
                    index += blobSize;
                    // Pad to 4-byte boundary
                    index += (4 - (index % 4)) % 4;
                    msg->argCount++;
                }
            }
        }

        return msg;
    }
};


void printOSCMessage(OSCDecoder::OSCMessage* msg);
void decodeOSCMessage(OSCDecoder::OSCMessage* msg);
void doOSC(void);

void printOSCMessage(OSCDecoder::OSCMessage* msg) {
    Serial.print("Address: ");
    Serial.println(msg->address);

    Serial.print("Type tag: ");
    Serial.println(msg->typeTag);

    if (msg->argCount > 0) {
        Serial.println("Arguments:");
        for (int i = 0; i < msg->argCount; i++) {
            const auto& arg = msg->args[i];
            Serial.print("  [");
            Serial.print(i);
            Serial.print("] ");

            switch (arg.type) {
                case 'i':
                    Serial.print("int: ");
                    Serial.println(arg.intValue);
                    break;
                case 'f':
                    Serial.print("float: ");
                    Serial.println(arg.floatValue);
                    break;
                case 's':
                    Serial.print("string: ");
                    Serial.println(arg.stringValue);
                    break;
                case 'b':
                    Serial.print("blob (");
                    Serial.print(arg.blobSize);
                    Serial.println(" bytes)");
                    break;
            }
        }
    }
    Serial.println();
}

// Current value of home switch
bool homeRaw = false;


// Control motor using info in the OSC message
void decodeOSCMessage(OSCDecoder::OSCMessage* msg) {
    // Serial.print("Address: ");
    // Serial.println(msg->address);
    String osc = msg->address;
    // Serial.printf("OSC address: %s \n", osc.c_str());

    if (osc.indexOf("/") != 0) {
        Serial.println("ERROR: Invalid OSC address format");
        return;
    }

    int cnt = 0;
    int i0 = 0;
    // extract up to 3 fields from the OSC address
    String oscField[3];
    for (int i=0; i<3; i++) {
        int i1 = osc.indexOf("/", i0+1);
        if (i1 == -1) {
            oscField[i] = osc.substring(i0+1);
            cnt++;
            break;
        }
        else {
            oscField[i] = osc.substring(i0+1, i1);
            cnt++;
        }
        i0 = i1;
    }

    if (oscField[0] != "motor") {
        Serial.println("ERROR: First OSC field is not \"motor\"");
        return;
    }

    calibrateHome = false;
    motorOn = false;
    motorOff = false;
    if(cnt == 2) {
        calibrateHome = oscField[1] == "home";
        motorOn = oscField[1] == "on";
        motorOff = oscField[1] == "off";
    }

    rotateTo0 = false;
    rotateTo90 = false;
    rotateTo180 = false;
    rotateTo270 = false;
    rotateNow = false;
    rotate90 = false;
    calibrateHome = false;
    rotate180 = false;
    if(cnt == 3) {
        if(oscField[1] == "rotate_to") {
          rotateTo0   = oscField[2] == "0";
          rotateTo90  = oscField[2] == "90";
          rotateTo180 = oscField[2] == "180";
          rotateTo270 = oscField[2] == "270";
          rotateNow   = oscField[2] == "now";
        }
        if(oscField[1] == "rotate") {
          rotate90  = oscField[2] == "90";
          rotate180 = oscField[2] == "90";
        }
    }
}

// activate the OSC messages already decoded
void doOSC(void) {

    if (motorOn) {
      digitalWrite(MOTOR_PIN, HIGH);
      motorState = MOTOR_ON;
      Serial.println("OSC Turn motor ON");
    }
    if (motorOff) {
      digitalWrite(MOTOR_PIN, LOW);
      motorState = MOTOR_OFF;
      Serial.println("OSC Turn motor OFF");
    }

    if (rotateTo0) {
      Serial.println("Rotate to the 0 (HOME) position");
      // check if already at home position
      if (homeRaw == false) {
        digitalWrite(MOTOR_PIN, HIGH);
        motorState = OSC_ROTATE_TO_0;
      } 
      else {
        digitalWrite(MOTOR_PIN, LOW);
        motorState = MOTOR_OFF;
        Serial.println("OSC rotation to 0 (home) complete");
        positionCountDuringRotation = 0;
      }
    }
    if (rotateTo90) {
      Serial.println("Rotate to the 90 position");
      digitalWrite(MOTOR_PIN, HIGH);
      motorState = OSC_ROTATE_TO_90;
    }
    if (rotateTo180) {
      Serial.println("Rotate to the 180 position");
      digitalWrite(MOTOR_PIN, HIGH);
      motorState = OSC_ROTATE_TO_180;
    }
    if (rotateTo270) {
      Serial.println("Rotate to the 270 position");
      digitalWrite(MOTOR_PIN, HIGH);
      motorState = OSC_ROTATE_TO_270;
    }
    if (rotate90) {
      Serial.println("Rotate 90 Deg");
      digitalWrite(MOTOR_PIN, HIGH);
      motorState = OSC_ROTATE_90;
    }
    if (rotate180) {
      Serial.println("Rotate 180 Deg");
      digitalWrite(MOTOR_PIN, HIGH);
      motorState = OSC_ROTATE_180;
    }
    if (rotate180) {
      Serial.println("Rotate 360 Deg");
      digitalWrite(MOTOR_PIN, HIGH);
      motorState = OSC_ROTATE_360;
    }

    if (rotateNow) {
      Serial.println("OSC Rotate now for the rotation degrees set on the web page");
      digitalWrite(MOTOR_PIN, HIGH);
      motorState = OSC_ROTATE_NOW;
      positionCountDuringRotation = 0;
    }
}

// Handle OSC messages
void checkOSC(void) {
    // // Check WiFi connection status and reconnect if needed
    // if (WiFi.status() != WL_CONNECTED) {
    //     Serial.println("WiFi disconnected! Attempting to reconnect...");
    //     connectToWiFi(storedSSID, storedPassword);
        
    //     // If reconnection fails, switch back to AP mode
    //     if (WiFi.status() != WL_CONNECTED) {
    //         Serial.println("Reconnection failed. Switching back to AP mode...");
    //         isAPMode = true;
    //         udpStarted = false;
    //         startAPMode();
    //         return; // Exit loop to allow AP mode to handle requests
    //     }
    // }
    
    // Start UDP listener if not already started
    if (!udpStarted) {
        if (udp.begin(OSC_PORT)) {
            Serial.print("Listening for OSC messages on port ");
            Serial.println(OSC_PORT);
            udpStarted = true;
        }
    }
    
    int packetSize = udp.parsePacket();
    if (packetSize) {
        led.ledBlink(1, 255, 100, 50, 0);
        // Serial.print("Received from ");
        // Serial.print(udp.remoteIP());
        // Serial.print(":");
        // Serial.println(udp.remotePort());

        // Read packet into buffer
        uint8_t buffer[1024];
        int len = udp.read(buffer, 1024);

        // Decode OSC message
        OSCDecoder::OSCMessage* msg = OSCDecoder::decodeMessage(buffer, len);
        if (msg != nullptr) {
            printOSCMessage(msg);
            decodeOSCMessage(msg);
            doOSC();
            // // The web page does not seem to be found to load in a browser
            // // messageHistory.add(formatOSCMessageForWeb(msg));
            delete msg;
        }
        else {
            Serial.println("Error decoding OSC message");
        }
    }
}

////////////////////////////////////////////////////////////////////////
// Platform switch stuff
unsigned long homeDetectTime = 0;
unsigned long lastHomeSwitchTime = 0;
unsigned long lastPositionSwitchTime = 0;

// Update limit switch states with debouncing
void updateSwitchStates() {
  // Time used for switch debounce
  unsigned long now = millis();
  
  // Read HOME switch
  homeRaw = digitalRead(HOME_SWITCH_PIN);
  if (homeRaw != homeSwitchLastState) {
    homeDetectTime = now;
    homeSwitchLastState = homeRaw;
  }
  
  // Debounce HOME switch
  if ((now - homeDetectTime) >= DEBOUNCE_TIME) {
    if (homeRaw && !homeSwitchDetected) {
      // LOW to HIGH transition detected
      homeSwitchDetected = true;
      lastHomeSwitchTime = now;
      Serial.println("HOME switch triggered");
      onHomeSwitchTriggered(now);
    }
    homeSwitchDetected = homeRaw;
  }
  
  // Read POSITION switch
  // MRW: OR in HOME switch to complete 4 quadrant positions
  bool positionRaw = digitalRead(POSITION_SWITCH_PIN) | homeRaw;
  if (positionRaw != positionSwitchLastState) {
    homeDetectTime = now;
    positionSwitchLastState = positionRaw;
  }
  
  // Debounce POSITION switch
  if ((now - homeDetectTime) >= DEBOUNCE_TIME) {
    if (positionRaw && !positionSwitchDetected) {
      // LOW to HIGH transition detected
      positionSwitchDetected = true;
      lastPositionSwitchTime = now;
      Serial.println("POSITION switch triggered");
      onPositionSwitchTriggered(now);
    }
    positionSwitchDetected = positionRaw;
  }
}

// Handle HOME switch trigger
void onHomeSwitchTriggered(unsigned long now) {
  if (motorState == HOMING) {
    homeCountDuringHome++;
    Serial.print("Home switch count during homing: ");
    Serial.println(homeCountDuringHome);
    
    if (homeCountDuringHome == 1) {
      positionCountDuringRotation = -1; 
    }
  } else if (motorState == OSC_ROTATE_TO_0) {
      digitalWrite(MOTOR_PIN, LOW);
      motorState = MOTOR_OFF;
      Serial.println("OSC rotation to 0 (home) complete");
      positionCountDuringRotation = 0;
  }
}

// Handle POSITION switch trigger for 90,180,270,360 rotations
void onPositionSwitchTriggered(unsigned long now) {
  
  if (motorState == PERIODIC_RUNNING) {
    // Count position switches during periodic rotation
    positionCountDuringRotation++;
    Serial.print("Position switch count during rotation: ");
    Serial.println(positionCountDuringRotation);
    
    // Check if we've reached the target rotation
    int targetPositionSwitches = periodicRotation / 90;
    if (positionCountDuringRotation >= targetPositionSwitches) {
      // Stop motor for next scheduled rotation
      digitalWrite(MOTOR_PIN, LOW);
      motorState = PERIODIC_WAITING;
      Serial.print("Periodic rotation complete, next in ");
      Serial.print(periodicPeriod);
      Serial.println(" seconds");
    }
  } else if (motorState == OSC_ROTATE_NOW) {
    // Count position switches during periodic rotation
    positionCountDuringRotation++;
    Serial.print("Position switch count during rotation: ");
    Serial.println(positionCountDuringRotation);
    
    // Check if we've reached the target rotation
    int targetPositionSwitches = periodicRotation / 90;
    if (positionCountDuringRotation >= targetPositionSwitches) {
      // Stop motor for next scheduled rotation
      digitalWrite(MOTOR_PIN, LOW);
      motorState = MOTOR_OFF;
      Serial.println("OSC rotation complete");
      positionCountDuringRotation = 0;
    }
  } else if (    (motorState == OSC_ROTATE_TO_90) 
              || (motorState == OSC_ROTATE_TO_180)
              || (motorState == OSC_ROTATE_TO_270) ) {
    int deg = 0;
    if(motorState == OSC_ROTATE_TO_90) deg = 90;
    else if(motorState == OSC_ROTATE_TO_180) deg = 180;
    else if(motorState == OSC_ROTATE_TO_270) deg = 270;

    // Count position switches during periodic rotation
    positionCountDuringRotation++;
    Serial.print("Position switch count during rotation: ");
    Serial.println(positionCountDuringRotation);
    
    // Check if we've reached the target rotation
    int targetPositionSwitches = deg / 90;
    if (positionCountDuringRotation >= targetPositionSwitches) {
      // Stop motor for next scheduled rotation
      digitalWrite(MOTOR_PIN, LOW);
      motorState = MOTOR_OFF;
      Serial.println("OSC rotation 180 complete");
    }

  }
}

////////////////////////////////////////////////////////////////////////
// Motor control stuff
unsigned long runCommandTime = 0;
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

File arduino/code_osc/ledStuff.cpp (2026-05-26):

#include "ledStuff.h"
#include <Arduino.h>

ledStuff::ledStuff(uint8_t pin) : ledPin(pin) {
    pinMode(ledPin, OUTPUT);
    analogWrite(ledPin, 0);
    blinkTaskHandle = nullptr;
}

void ledStuff::setIntensity(uint8_t intensity) {
    analogWrite(ledPin, intensity);
}

void ledStuff::blinkTask(void* parameter) {
    BlinkParams* params = (BlinkParams*)parameter;
    uint8_t ledPin = params->ledPin;
    
    // If all times are 0, just set to low intensity and finish
    if (params->highTime == 0 && params->lowTime == 0) {
        analogWrite(ledPin, params->lowBrightness);
        delete params;
        while(1) vTaskDelay(pdMS_TO_TICKS(100));
      //  vTaskDelete(NULL);
      //  return;
    }
    
    // Perform blink pattern
    for (int i = 0; i < params->numBlinks; i++) {
        // High brightness phase
        analogWrite(ledPin, params->highBrightness);
        vTaskDelay(pdMS_TO_TICKS(params->highTime));
        
        // Low brightness phase
        analogWrite(ledPin, params->lowBrightness);
        vTaskDelay(pdMS_TO_TICKS(params->lowTime));
    }
    
    // Ensure LED ends at low intensity
    analogWrite(ledPin, params->lowBrightness);
    
    delete params;
    while(1) vTaskDelay(pdMS_TO_TICKS(100));
//    vTaskDelete(NULL);
}

void ledStuff::doubleBlinkTask(void* parameter) {
    BlinkParams* params = (BlinkParams*)parameter;
    uint8_t ledPin = params->ledPin;
    
    // If all times are 0, just set to low intensity and finish
    if (params->highTime == 0 && params->lowTime == 0 && 
        params->secondHighTime == 0 && params->secondLowTime == 0) {
        analogWrite(ledPin, params->lowBrightness);
        delete params;
        while(1) vTaskDelay(pdMS_TO_TICKS(100));
        // vTaskDelete(NULL);
        // return;
    }
    
    // Perform double blink pattern cycles
    for (int cycle = 0; cycle < params->numBlinks; cycle++) {
        // First high
        if (params->highTime > 0) {
            analogWrite(ledPin, params->highBrightness);
            vTaskDelay(pdMS_TO_TICKS(params->highTime));
        }
        
        // First low
        if (params->lowTime > 0) {
            analogWrite(ledPin, params->lowBrightness);
            vTaskDelay(pdMS_TO_TICKS(params->lowTime));
        }
        
        // Second high
        if (params->secondHighTime > 0) {
            analogWrite(ledPin, params->secondHighBrightness);
            vTaskDelay(pdMS_TO_TICKS(params->secondHighTime));
        }
        
        // Second low
        if (params->secondLowTime > 0) {
            analogWrite(ledPin, params->secondLowBrightness);
            vTaskDelay(pdMS_TO_TICKS(params->secondLowTime));
        }
    }
    
    // Ensure LED ends at low intensity
    analogWrite(ledPin, params->secondLowBrightness);
    
    delete params;
    while(1) vTaskDelay(pdMS_TO_TICKS(100));
    //  vTaskDelete(NULL);
}

void ledStuff::ledBlink(int numBlinks, 
                        uint8_t highBrightness, 
                        uint16_t highTime,
                        uint8_t lowBrightness, 
                        uint16_t lowTime) {
    // Stop any existing blink task
    if (blinkTaskHandle != nullptr) {
        vTaskDelete(blinkTaskHandle);
        blinkTaskHandle = nullptr;
    }
    
    // Create parameters struct
    BlinkParams* params = new BlinkParams();
    params->ledPin = ledPin;
    params->highBrightness = highBrightness;
    params->highTime = highTime;
    params->lowBrightness = lowBrightness;
    params->lowTime = lowTime;
    params->numBlinks = numBlinks;
    params->isDoubleBlink = false;
    
    // Create task
    xTaskCreate(blinkTask, 
                "ledBlink", 
                2048, 
                params, 
                2, 
                &blinkTaskHandle);
}

void ledStuff::doubleBlinkPattern(int numCycles,
                                  uint8_t firstHighBrightness,
                                  uint16_t firstHighTime,
                                  uint8_t firstLowBrightness,
                                  uint16_t firstLowTime,
                                  uint8_t secondHighBrightness,
                                  uint16_t secondHighTime,
                                  uint8_t secondLowBrightness,
                                  uint16_t secondLowTime) {
    // Stop any existing blink task
    if (blinkTaskHandle != nullptr) {
        vTaskDelete(blinkTaskHandle);
        blinkTaskHandle = nullptr;
    }
    
    // Create parameters struct
    BlinkParams* params = new BlinkParams();
    params->ledPin = ledPin;
    params->highBrightness = firstHighBrightness;
    params->highTime = firstHighTime;
    params->lowBrightness = firstLowBrightness;
    params->lowTime = firstLowTime;
    params->secondHighBrightness = secondHighBrightness;
    params->secondHighTime = secondHighTime;
    params->secondLowBrightness = secondLowBrightness;
    params->secondLowTime = secondLowTime;
    params->numBlinks = numCycles;
    params->isDoubleBlink = true;
    
    // Create task
    xTaskCreate(doubleBlinkTask, 
                "doubleBlinkPattern", 
                2048, 
                params, 
                2, 
                &blinkTaskHandle);
}

void ledStuff::stopBlink(uint8_t finalIntensity) {
    if (blinkTaskHandle != nullptr) {
        vTaskDelete(blinkTaskHandle);
        blinkTaskHandle = nullptr;
    }
    analogWrite(ledPin, finalIntensity);
}

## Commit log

2026-02-21 init on off
    [Dicotomy-CenterHousing.3mf, Dicotomy-CenteringRing.3mf, Dicotomy-HumpCurved.3mf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]
2026-02-21 Fixed schematic. Added S2 mini pin jpeg to README
    [Dicotomy.kicad_sch]
2026-02-22 Update schematic with tran types and resistor values Created add_rotate.md requirements which are additions to the code_onoff.md requirements and used AI to create code_rotate.ino The basis of the co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
    [Dicotomy.kicad_sch]
2026-02-22 Changed add_rotate.md to be simpler, the periodic rotation can only be incriments of 90 degrees. AI replaced code_rotate.ino with new code. I forgot to tell AI to use the HOME switch as one of the 4 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
    [code_rotate.ino]
2026-02-22 Add code to turn on LED=255 while motor is runing and LED=50 when not running OR the HOME switch with the POSITION switch so that all 4 90 deg positions are triggered Start position count at -1 after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
2026-02-22 Add motor ON and OFF buttons to web page that un-conditionally turn the motor ON or OFF. A MOTOR_ON state is added
2026-02-23 Created 3D electracal mount Increased max time between 90 deg switch triggers when measuring RPM
    [Dicotomy-ElecMount.3mf, Dicotomy.FCStd]
2026-02-24 Corrected RPM and estimated time calculations Fixed periodic rotation with home offset
    [code_rotate.ino]
2026-02-28 added limit switch protector 3D to try to protect it during transport
    [Dicotomy-SwichProtectorClips.3mf, Dicotomy-SwitchProtector.3mf, Dicotomy-clip.3mf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]
2026-05-26 Added 3D CAD and gcode files new code_osc file which succesfully is receiving OSC commands from a MAC via Qlab
    [Dicotomy-FinAttach.3mf, Dicotomy-FinAttachBot.3mf, Dicotomy-FinAttachTop.3mf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]
2026-05-26 decoded OSC messages, not activated motor from OSC.
2026-05-26 Simplified code by removing homing offset and only supporting 90,180,270,360 rotations
2026-06-21 new 3D printed files
    [Dicotomy-FinAttachBot.3mf, Dicotomy-FinAttachTop.3mf, Dicotomy-HouseWallTubeAttach.3mf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]
